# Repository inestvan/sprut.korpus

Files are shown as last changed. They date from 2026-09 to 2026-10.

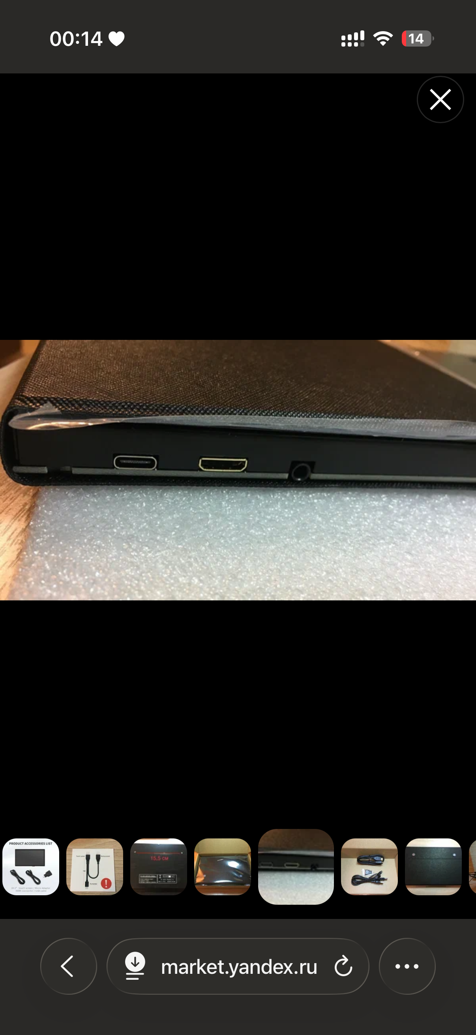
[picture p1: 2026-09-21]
docs/monitor/displayA_side_ports.png

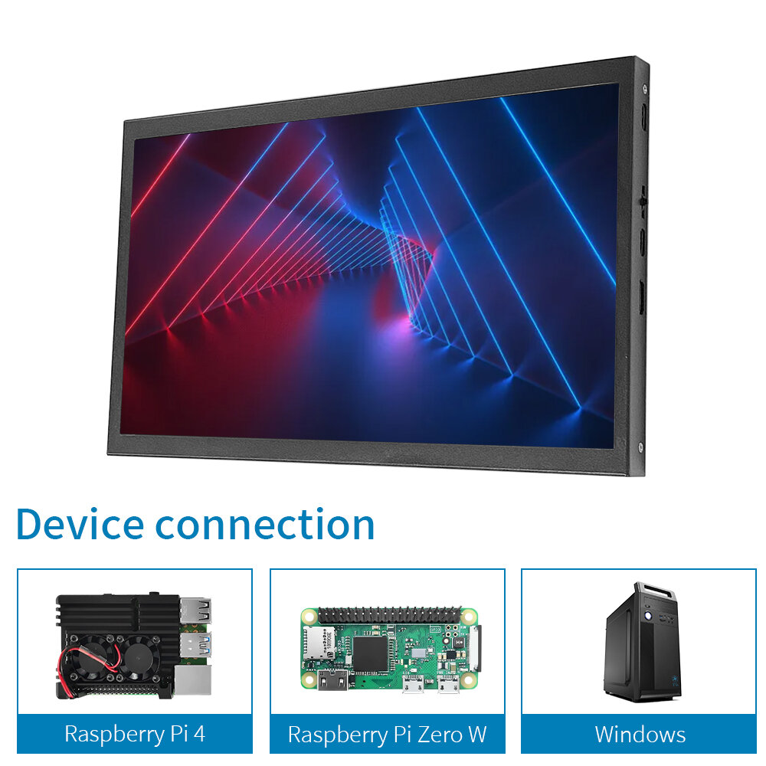
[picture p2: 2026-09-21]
docs/monitor/other_variant/jrp1133_front_angle.jpg

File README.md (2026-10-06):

# SPRUT — корпус изделия (10.1" монитор + Raspberry Pi 4B)

Печать: **Creality K2 Plus, PETG**. Модель параметрическая (OpenSCAD), все размеры
компонентов вынесены в начало файла `cad/sprut_korpus.scad`.

| Файл | Что это |
|---|---|
| `cad/sprut_korpus.scad` | исходник модели, параметры в начале файла |
| `stl/sprut_box.stl` | коробка (задняя стенка + борта), печатать как есть |
| `stl/sprut_bezel.stl` | лицевая рамка, уже развёрнута лицом вниз |
| `preview/*.png` | рендеры для проверки |
| `preview/scheme_placement.png` | схема: что куда ставится в корпусе (исходник `docs/scheme_placement.svg`) |
| `preview/scheme_wiring.png` | схема проводки и порядок сборки (исходник `docs/scheme_wiring.svg`) |
| `tools/diagrams/` | генераторы схем: `python3 tools/diagrams/wiring.py` пишет SVG в `docs/`, `node tools/diagrams/shot.mjs` делает PNG |
| `docs/components.md` | размеры компонентов, источники, что нужно проверить |

Наружный габарит при текущих параметрах: **272.2 x 153.4 x 59 мм** (Ш x В x Г).
Оба STL помещаются на стол K2 Plus (350 x 350) одновременно.

## Конструкция

Две детали, монитор загружается **спереди**:

1. **Коробка** — открыта спереди. На задней стенке: 4 стойки Raspberry Pi
   (M2.5), два держателя-«кармана» для DC-DC и RS485 (плата вдвигается в пазы),
   вентиляционные щели, отверстия VESA 100 (M4). Raspberry Pi полностью
   внутри корпуса, наружу её порты не выходят. Плата прижата к ВЕРХНЕМУ борту
   стороной microSD, а перед её разъёмами USB и Ethernet освобождено
   **55.9 мм** — туда заходят вилки с кабелями (USB-A с хвостовиком 40–45 мм,
   RJ45 с колпачком около 47 мм). Схема компоновки: `preview/layout_top.png`.
   Если понадобится вывести порты Pi наружу, поставь `pi_ports_window = true`:
   плата придвинется к нижнему борту и в нём появится окно 54.3 x 20.1 мм.
   В нижнем борту: вырез XT60E-M с двумя отверстиями под винты, отверстие BNC,
   окно RJ45, вентиляция. В верхнем борту — вентиляция.
   По левому и правому краю — каналы шириной 8 мм с шестью бобышками под
   резьбовые вставки M3. Внутренние стенки каналов и полки по длинным
   бортам держат монитор на нужной глубине.
   Разъёмы монитора («10 inch portable display», Display-A) стоят на **правом**
   торце (вид спереди): Type-C, mini HDMI, гнездо наушников. Поэтому справа вместо узкого канала
   сделан **отсек шириной 18 мм** под угловые штекеры. На уровне монитора с
   этой стороны стенки нет вообще: внутренняя стенка поднимается только до
   плоскости полки. Бобышки справа только по углам. По X монитор держит
   ребро 2.5 мм на лицевой рамке — оно остаётся выше штекера. Ниже полки в
   стенке окно 5–80 мм от нижнего края: через него проходят кабели монитора
   и штекеры micro-HDMI/USB-C Pi. Сенсорные кнопки
   монитора на его задней панели в корпусе недоступны — яркость выставить до
   сборки (см. docs/components.md).
   Raspberry Pi стоит со стороны разъёмов монитора: её micro-HDMI и USB-C
   смотрят в окно отсека, перед ними свободно 35 мм до наружного борта
   (`pi_hdmi_free`), HDMI-шлейф до монитора 15–20 см. Порты USB/Ethernet
   смотрят к верхнему борту, перед ними свободно 55.9 мм под вилки.
   Держатели DC-DC и RS485 стоят компактным блоком у нижнего борта левее Pi,
   платы вдвигаются сверху. Крепление VESA 100 сдвинуто на 16 мм влево
   (`vesa_dx`), чтобы отверстия не попадали под плату Pi. Разъёмы XT60,
   BNC, RJ45 — в левой части нижнего борта.
   Параметры: `mon_conn_side`, `mon_conn_y`, `bay_w`, `bezel_rib_h`,
   `wheel_slot`, `bay_boss_extra`.
2. **Лицевая рамка** — 3 мм, окно экрана с фаской 45°, 5 винтов M3 с потаем,
   ребро 2.5 мм вдоль торца монитора со стороны отсека разъёмов.

Порядок сборки: вставки M3 в бобышки (паяльник) → Pi на стойки (торцом USB к
нижнему борту, компонентами к экрану) → DC-DC и RS485 вдвинуть в держатели →
XT60/BNC/RJ45 в нижний борт → DC-DC и RS485 вдвинуть в держатели сбоку →
на монитор надеть угловые HDMI и Type-C, кабели
пропустить через окно во внутренней стенке за монитор → монитор положить спереди на полки (по периметру
рекомендую двусторонний вспененный скотч 1 мм) → рамка на 5 винтов M3x8.

## Что обязательно проверить перед печатью

Полный список с размерами и источниками — в `docs/components.md`. Коротко:

- **Монитор.** Заложен замер владельца: 237.2 x 145.4 x 14.5 мм (полная
  толщина, задняя сторона считается плоской — монитор лежит задней кромкой
  на полках шириной 2.5 мм). Активная область не замерялась: окно рамки
  224 x 126.5 по центру. Если светящаяся область смещена относительно
  габарита или задняя сторона не плоская (плата драйвера выступает бугром,
  а по краю толщина меньше) — сообщи, поправлю `view_dx/view_dy` и полки.
- **Разъёмы монитора.** Сторона и координаты сняты с фото с Маркета
  (см. `docs/components.md`, точность ±3 мм): правый торец, Type-C 25,
  mini HDMI 45, наушники 65 мм от низа. Один Type-C несёт и питание, и тач.
  Кабели — только **угловые** (90°) или плоские FPC-шлейфы: прямой HDMI-штекер
  требует ~40 мм и в отсек не влезет.
- **DC-DC 60V/3A (CR-6030L).** Точных размеров в сети нет; по фото и листингу
  ~43 x 21 мм, высота ~14 мм с конденсаторами. Держатель параметрический
  (`dcdc_l, dcdc_w`), подстрой под замер.
- **RS485-TTL.** 34 x 18 x 9 мм (с фото продавца) — заложено. Просвет паза
  держателя 18.9 мм (плата + 0.9), есть заходная фаска. Параметры `rs_gap_w`,
  `rs_gap_t`, `rs_lead`.
- **DC-DC.** Держатель оставлен как в первой версии (просвет 21.35, плата
  + 0.35, без фаски) — плата села хорошо. Параметры `dcdc_gap_w`,
  `dcdc_gap_t`, `dcdc_lead`, они независимы от RS485.
- **RJ45.** Гнездо на фото — под пайку в плату (8P8C, 15.9 x 21.6 x 13.4).
  Заложено окно 16.8 x 14.3 мм; само гнездо нужно припаять на плату и
  закрепить у стенки. Если возьмёшь панельный RJ45 (keystone / проходной с
  фланцем), скажи — заменю вырез.
- **BNC.** Заложено круглое отверстие Ø9.9 под резьбу 3/8"-32. Если у твоего
  разъёма есть лыска против проворота, поставь `bnc_flat = 9.0` (D-отверстие).

## Печать (K2 Plus, PETG)

- Сопло 0.4, слой 0.2, стенки 4 периметра (1.6 мм), верх/низ 5 слоёв,
  заполнение 25–30 % gyroid.
- Коробка — задней стенкой вниз (как в STL), **без поддержек**: стойки,
  бобышки и держатели вертикальные, полки под монитор с фаской 45°, окна в
  бортах перекрываются мостами до 55 мм (окно портов Pi) — для PETG
  включи охлаждение мостов.
- Рамка — лицом вниз (как в STL), без поддержек. Для гладкого лица —
  гладкий PEI лист. Потай под винты печатается конусом вверх.
- Держатель RS485 имеет заходную фаску 4 мм на открытом конце; у DC-DC
  фаски нет, он повторяет первую версию.
- Резьбовые вставки M3 (OD 4.5–4.6, длина 5–6): отверстие 4.0 мм.
  Саморезы Pi M2.5 в отверстие 2.2 мм. XT60 — саморезы M3 в отверстие 2.5 мм
  (или поставь `xt_screw_d = 3.2` под болт с гайкой).
- Температура сопла PETG 240–250 °C, стол 75–80 °C, клей/лак на стол,
  дверь принтера закрыть.

## Крепёж

| Позиция | Кол-во |
|---|---|
| Вставка резьбовая M3 (OD 4.5, L 5–6) | 5 |
| Винт M3x8 потайной | 5 |
| Саморез M2.5x6 (Pi) | 4 |
| Саморез M3x8 (XT60E-M) | 2 |
| Винт M4 (VESA 100) | 4, по желанию |

## Проверка геометрии

`tools/verify_stl.py` режет STL плоскостями и сверяет размеры проёма под
монитор, стоек Pi, вырезов в нижнем борту, окна рамки, отверстий под винты
и пазов держателей с заданными значениями.

## Регенерация STL

```bash
openscad -o stl/sprut_box.stl   -D 'part="box"'   cad/sprut_korpus.scad
openscad -o stl/sprut_bezel.stl -D 'part="bezel"' cad/sprut_korpus.scad
```

## Как закреплён монитор

Без винтов: монитор зажат между полками коробки (сзади) и лицевой рамкой
(спереди), по бокам его держат борта и внутренние стенки каналов с зазором
1 мм. Со стороны разъёмов внутренняя стенка и полка прерваны окном под
кабели, монитор там держат участки стенки выше и ниже окна. Разрезы — `preview/section_y.png` и `preview/section_x.png`.
Между рамкой и монитором заложен зазор 0.3 мм: проложи по периметру
вспененный двусторонний скотч 0.5–1 мм, он выберет зазор и защитит стекло.

Разрезы генерируются из `cad/slice.scad` (параметры `which`, `axis`, `pos`):

```bash
openscad -o sec.svg -D 'which="box"' -D 'axis="y"' -D 'pos=76.7' cad/slice.scad
```

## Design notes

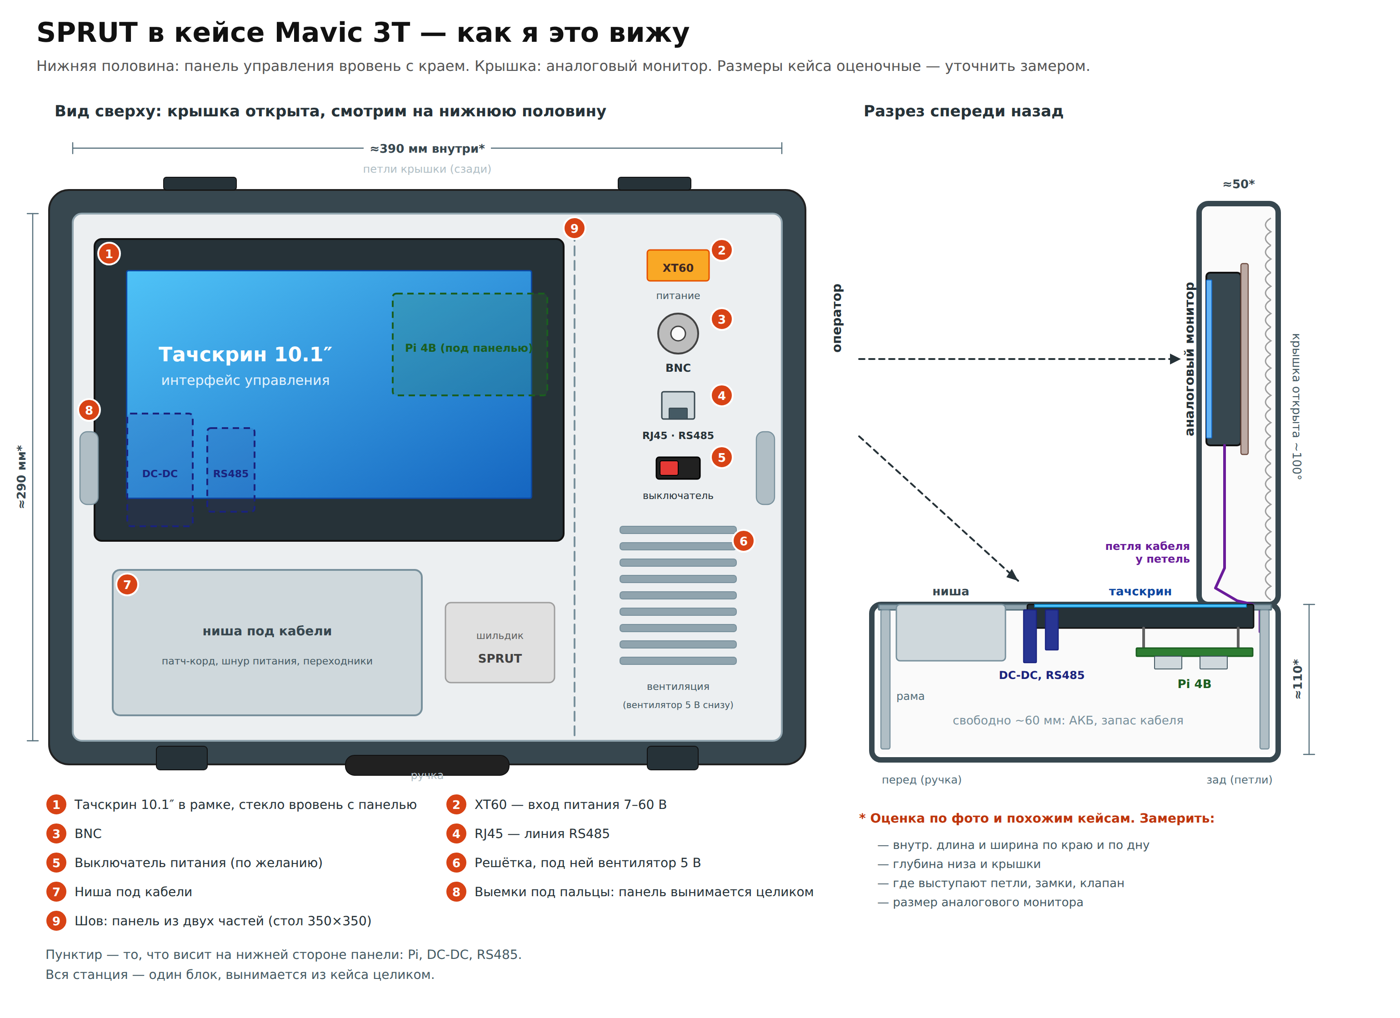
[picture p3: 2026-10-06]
preview/case_mavic3t_concept.png

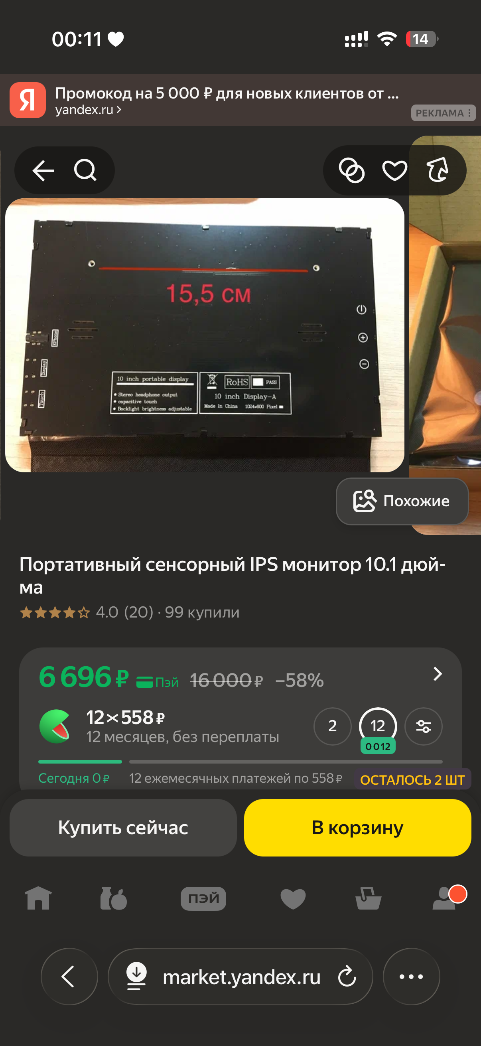
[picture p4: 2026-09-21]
docs/monitor/displayA_back_yandex.png

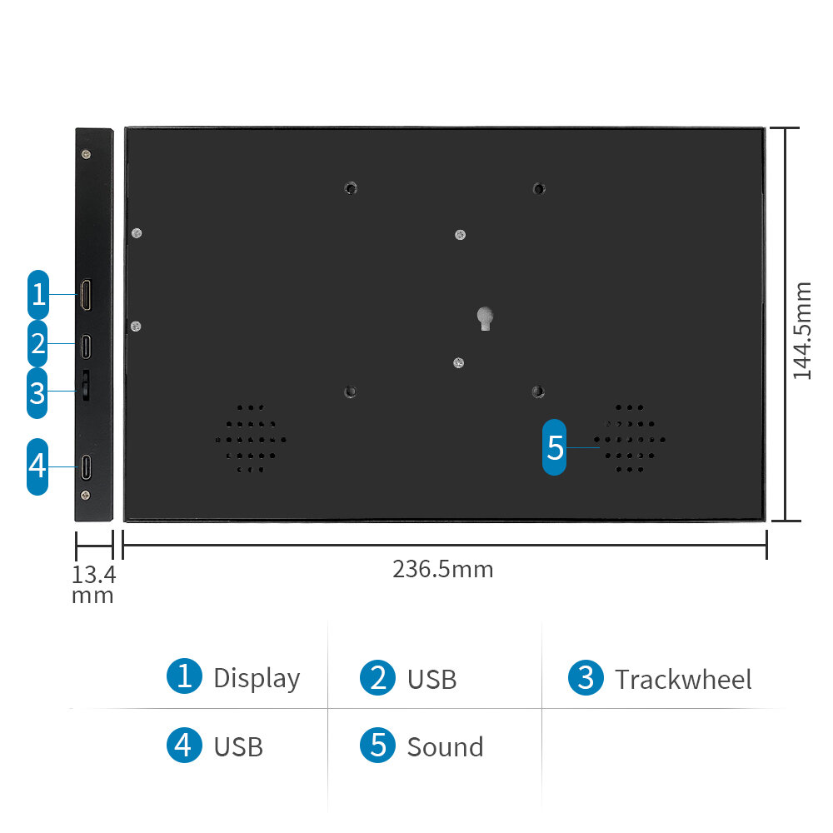
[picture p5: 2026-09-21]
docs/monitor/other_variant/jrp1133_back_ports.jpg

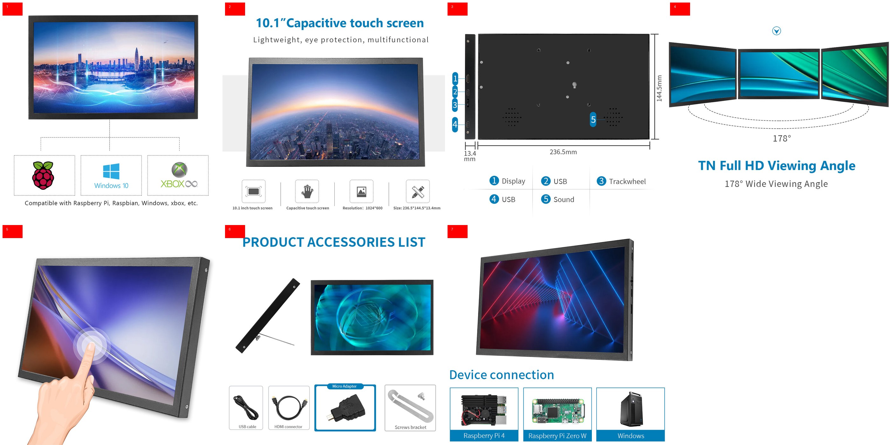
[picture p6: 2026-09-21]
docs/monitor/other_variant/jrp1133_all_photos.jpg

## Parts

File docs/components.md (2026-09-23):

# Компоненты: размеры, источники, что уточнить

Статус: ✅ по даташиту / официальному чертежу, ⚠️ оценка (нужен замер), ❌ не найдено.

## Raspberry Pi 4 Model B ✅

Источник: официальный datasheet, Release 1.1 (март 2024), раздел
«Mechanical Specification».

| Параметр | Значение |
|---|---|
| Плата | 85 x 56 мм, радиус углов 3 мм, толщина 1.6 |
| Отверстия | 4 x Ø2.7 (M2.5), сетка 58 x 49, отступ от краёв 3.5 |
| USB-C | центр 11.2 от левого края, высота 3.2 |
| micro-HDMI 0 / 1 | центры 26.0 и 39.5, высота 3.0 |
| Аудио 3.5 | центр 54.0, высота 6.0 |
| Правый торец: USB2 | центр 9.0 от нижнего края, 13.1 x 16.0 |
| Правый торец: USB3 | центр 27.0, 13.1 x 16.0 |
| Правый торец: Ethernet | центр 45.75, 16.0 x 13.5 |
| Выступ USB/ETH за край | ~2.5 |
| GPIO 2x20 | центр 32.5 от левого края, высота 8.5 |

В модели: Pi лежит на задней стенке коробки на стойках 6 мм, компонентами к
экрану, полностью внутри корпуса. Стоит у ПРАВОЙ стенки, со стороны разъёмов
монитора (`pi_near_bay = true`), повёрнута так, что длинный торец с
USB-C / micro-HDMI / аудио смотрит в окно стенки отсека.

| Параметр | Значение |
|---|---|
| Плата занимает | X 178.2…234.2, Y 7…92 |
| Торец micro-HDMI до стенки отсека | 18 мм |
| Свободно перед micro-HDMI / USB-C до наружного борта | 35 мм (сквозь окно в отсек), `pi_hdmi_free` |
| USB-C / micro-HDMI 0 / micro-HDMI 1 / аудио | Y 18.2 / 33 / 46.5 / 61 |
| Разъёмы монитора Type-C / mini HDMI | Y 29 / 49 |
| Край microSD до нижнего борта | 4 мм (карта выступает ~2.5) |
| Торцы USB/Ethernet | Y 94.5, свободно до верхнего борта 55.9 мм |

HDMI от Pi до монитора: micro-HDMI Pi на Y 33 или 46.5, mini-HDMI монитора
на Y 49 и выше на 30 мм по глубине. Перед разъёмами Pi 35 мм — влезает и
обычный прямой micro-HDMI штекер с хвостовиком. Шлейф 15–20 см, со стороны
монитора угловой mini-HDMI.

Крепление VESA 100 сдвинуто на 16 мм влево (`vesa_dx`): иначе нижнее правое
отверстие приходилось под плату Pi, прямо под выводы GPIO.
USB/Ethernet по-прежнему втыкаются изнутри, для них оставлено 55.9 мм.

Кнопки монитора (на его задней панели у левого края) теперь над пустым
участком задней стенки корпуса — при желании там можно сделать лючок.

## XT60E-M (Amass) — панельный, папа ✅

Источник: чертёж Amass XT60E-M (Changzhou Amass Electronics).

| Параметр | Значение |
|---|---|
| Фланец | 27.0 x 8.1 |
| Крепёжные отверстия | 2 x Ø3.0, межцентровое 20.0 |
| Тело (вырез в панели) | 15.5 x 8.1, углы скошены |
| Глубина за фланцем | 9.5 (корпус) + 4.0 (контакты) |
| Полная длина | 16.7 |
| Контакты | Ø4.3, шаг 7.2 |

В модели: вырез 16.1 x 8.7 (зазор 0.3), отверстия Ø2.5 под саморез M3.

## Расположение держателей DC-DC и RS485

Компактный блок вплотную к нижнему борту, левее Raspberry Pi и отверстия
VESA, длинной стороной вдоль высоты корпуса. Платы вдвигаются сверху (со
стороны верхнего борта), торцевые упоры внизу. DC-DC ближе к Pi, RS485 ближе
к RJ45.

| Держатель | Основание X | Основание Y | Просвет паза |
|---|---|---|---|
| RS485 | 118.7…139.6 | 4…44 | 18.9 x 2.0 |
| DC-DC | 141.6…164.9 | 4…53 | 21.35 x 1.95 |

Над блоком свободная зона 46 x 42 мм для вдвигания плат, в задней стенке
там пять вентиляционных щелей. Отверстие VESA (170.1, 26.7) в 3 мм правее
блока и в 6 мм левее Pi.

## RS485-TTL модуль ⚠️ (размеры с фото продавца)

34 x 18 мм, высота 9 мм (DC-DC изолятор — самый высокий элемент). Крепёжных
отверстий на фото нет, поэтому в модели держатель-«карман»: плата вдвигается
в пазы сбоку, торцевой упор с одной стороны, на открытом конце заходная
фаска 4 мм. Зазоры: по ширине 0.9 мм суммарно (`rs_gap_w`), по толщине
0.4 мм (`rs_gap_t`). Просвет паза 18.9 x 2.0 мм. У DC-DC свои параметры
(`dcdc_gap_w` 0.35, `dcdc_gap_t` 0.35, без фаски), просвет 21.35 x 1.95 —
как в первой версии, плата села хорошо.

## DC-DC 60V/3A buck, маркировка CR-6030L ⚠️

По маркировке платы «60V/3A 降压模块», два электролита (100 мкФ 63 В и
330 мкФ 35 В), дроссель 22 мкГн. Листинг на AliExpress (1005006203232387)
даёт только «4 x 2 x 1 см, 15 г». Точного чертежа в сети нет.

Моя оценка по фото (по диаметру конденсаторов 8 мм): **43 x 21 мм, высота
~14 мм** (конденсаторы 12 + плата 1.6). Два отверстия Ø3 по диагонали
(у IN+ и у OUT−). Просьба замерить: длину, ширину, высоту, и есть ли
отверстия. В модели держатель-«карман» с параметрами `dcdc_l`, `dcdc_w`,
`dcdc_pcb_t`, `dcdc_comp_h`.

## Монитор 10.1" «10 inch portable display / Display-A» ✅ (по фото владельца)

Точная модель найдена владельцем на Яндекс Маркете (карточка 102591172820,
«Портативный сенсорный IPS монитор 10.1 дюйма»). Скриншоты в `docs/monitor/`:
вид сзади, торец с разъёмами, размеры спереди. На задней панели шелкография
«10 inch portable display — Stereo headphone output, capacitive touch,
Backlight brightness adjustable» и «10 inch Display-A, 1024x600».
Производитель не указан, это безымянный OEM; чертежей в сети нет, а
одноимённые серии Elecrow «Display-H/B» — другие изделия (micro-USB, 20 мм).
Ранее найденный KEPIFO JRP1133 (папка `other_variant`) — похожий, но другой
вариант платы: у него колёсико и два Type-C, у этого их нет.

| Параметр | Значение | Источник |
|---|---|---|
| Габарит по продавцу | 235 x 143 | фото с линейкой |
| Габарит по замеру владельца | 237.2 x 145.4 x 14.5 | замер (заложено) |
| Экран | IPS 1024x600, ёмкостный тач 5 точек | шелкография |
| Крепёжные отверстия сзади | 2 шт, шаг 155 мм, на 29 мм от верхнего края, 40 мм от левого (вид сзади) | фото |
| Кнопки | сенсорные ⏻ / + / − на ЗАДНЕЙ панели, у левого края (вид спереди), ~9 мм от края, 48 / 66 / 84 мм от низа | фото |

**Порты — на ПРАВОМ торце (вид спереди)**, по центру толщины. Координаты от
НИЖНЕГО края монитора, точность ±3 мм (сняты с фото задней панели):

| Элемент | От нижнего края | Назначение |
|---|---|---|
| Type-C («Touch») | 25 | питание 5 В и тачскрин по одному кабелю |
| mini HDMI («Display», гнездо 11.2 мм) | 45 | видео |
| Гнездо 3.5 мм («Earphone») | 65 | наушники, не используется |

Что заложено в модель: `mon_conn_side = "right"`, отсек 18 мм без стенки на
уровне монитора, окно под кабели в стенке ниже полки на 12…80 мм от нижнего
края, прорезь под колёсико отключена (`wheel_slot = false`).

**Важно про кнопки.** Питание, «+» и «−» — сенсорные площадки на задней
панели монитора. В закрытом корпусе задняя панель смотрит внутрь, к Pi, и
кнопки недоступны. Обычно такие мониторы включаются сами при подаче питания
и помнят яркость — выставь яркость до окончательной сборки. Если нужен
доступ, скажи: можно сделать лючок в задней стенке напротив кнопок, но там
сейчас стоит Raspberry Pi, её придётся сдвинуть.

## RJ45 ⚠️

На фото — гнездо 8P8C под пайку в плату (типовое: 15.9 x 21.6 x 13.4,
окно под вилку ~12 x 12). В модели окно в борту 16.8 x 14.3 (зазор 0.4).
Гнездо нужно закрепить на плате, прижатой к борту изнутри. Альтернатива —
панельный проходной RJ45 (keystone, вырез 14.5 x 16.0 или фланцевый
D-типа) — заменю вырез по запросу.

## BNC панельный ✅/⚠️

Стандарт для BNC bulkhead с резьбой 3/8"-32 UNEF: отверстие Ø9.5–9.7,
D-образное с лыской 9.0 (у части разъёмов лыски нет). Толщина панели 3 мм
проходит по длине резьбы (~7 мм с гайкой, гровером и лепестком).
В модели: круглое Ø9.9 (`bnc_flat = 0`); для D-отверстия — `bnc_flat = 9.0`.

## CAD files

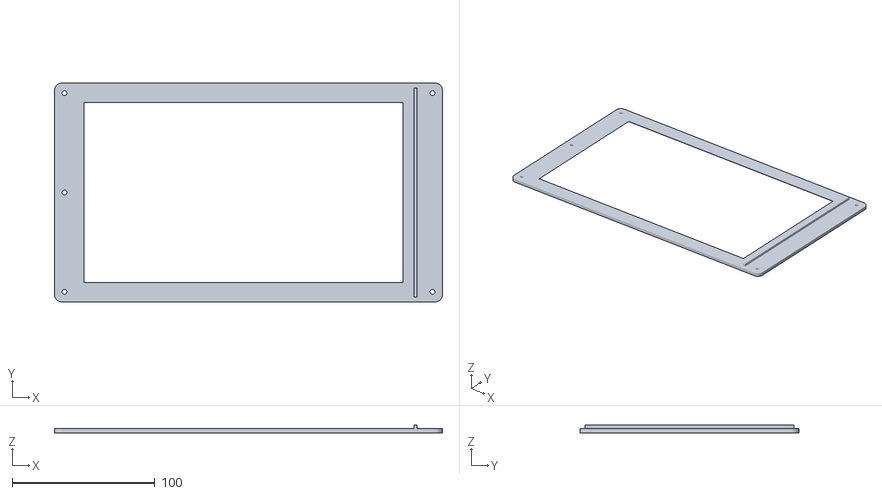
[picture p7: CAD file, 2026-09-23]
stl/sprut_bezel.stl
272.2 x 153.4 x 5.50

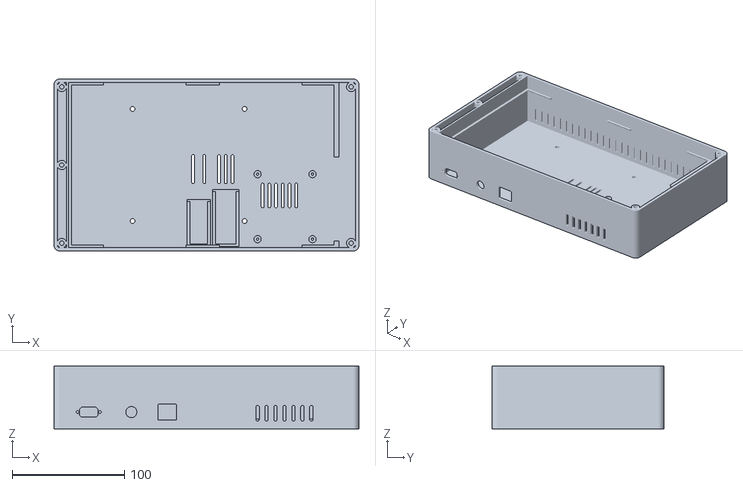
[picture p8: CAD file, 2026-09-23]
stl/sprut_box.stl
272.2 x 153.4 x 56.0

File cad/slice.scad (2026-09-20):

use </home/user/sprut.korpus/cad/sprut_korpus.scad>
which = "box";   // box | bezel | mon | pi | cards
axis  = "y";     // y: разрез плоскостью Y=pos ; x: плоскостью X=pos
pos   = 76.7;
module sel() {
  if (which == "box")   box();
  if (which == "bezel") bezel_world();
  if (which == "mon")   ghost_monitor();
  if (which == "pi")    ghost_pi();
  if (which == "cards") ghost_cards();
  if (which == "plugs") ghost_plugs();
}
// результат: 2D, X = координата вдоль разреза, Y = глубина Z корпуса
if (axis == "y") projection(cut=true) rotate([-90, 0, 0]) translate([0, -pos, 0]) sel();
else             projection(cut=true) rotate([-90, 0, 0]) rotate([0, 0, -90]) translate([-pos, 0, 0]) sel();

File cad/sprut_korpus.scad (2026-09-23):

// =====================================================================
//  SPRUT — корпус: 10.1" монитор + Raspberry Pi 4B + DC-DC 60V buck
//  + RS485-TTL + XT60E-M + RJ45 + BNC
//
//  Печать: Creality K2 Plus, PETG. Все размеры в мм.
//
//  Конструкция из двух деталей:
//    "box"   — коробка: задняя стенка + 4 борта, открыта СПЕРЕДИ. На задней
//              стенке стойки Pi и держатели модулей; в бортах вырезы под
//              разъёмы; по бокам два канала с бобышками под вставки M3.
//              Монитор укладывается спереди на полки, затем прикручивается
//              лицевая рамка. Печатать как смоделирована (задней стенкой вниз).
//    "bezel" — лицевая рамка с окном экрана, 6 винтов M3 с потаем.
//              В STL уже развёрнута лицевой стороной вниз.
//    "assembly" — сборка с макетами компонентов (только для просмотра).
//
//  Система координат: X — ширина, Y — высота (вид спереди), Z — от наружной
//  плоскости задней стенки (Z=0) к лицевой рамке.
// =====================================================================

part = "assembly";   // [box, bezel, assembly]

$fn = 48;
eps = 0.01;

// ---------------------------------------------------------------------
// ПАРАМЕТРЫ — печать / стенки
// ---------------------------------------------------------------------
wall     = 3.0;    // толщина бортов
back_t   = 3.0;    // толщина задней стенки
bezel_t  = 3.0;    // толщина лицевой рамки
corner_r = 5.0;    // радиус наружных углов (вид спереди)
clr      = 1.0;    // зазор монитор/стенки на сторону
ch_w     = 8.0;    // ширина боковых каналов под бобышки (= диаметр бобышки)
in_wall  = 2.0;    // толщина внутренней стенки канала
shelf_w  = 2.5;    // ширина полки под край монитора

// ---------------------------------------------------------------------
// ПАРАМЕТРЫ — монитор 10.1" 1024x600 (JRP1133 DCT)
// Габарит по замеру владельца: 237.2 x 145.4 x 14.5 мм (толщина полная,
// задняя сторона считается плоской — монитор лежит задней кромкой на полках).
// Активная область не замерялась: окно = типовые 222.7 x 125.3 + 1 мм,
// по центру. Если светящаяся область смещена — поправь view_dx / view_dy.
// ---------------------------------------------------------------------
mon_w   = 237.2;   // ширина монитора (габарит)
mon_h   = 145.4;   // высота
mon_t   = 14.5;    // полная толщина монитора
view_w  = 224.0;   // окно в рамке (активная область + ~1 мм)
view_h  = 126.5;
view_dx = 0.0;     // смещение окна от центра панели (+ вправо)
view_dy = 0.0;     // (+ вверх)
drv_zone = 12.0;   // свободная глубина за монитором под кабели
// Разъёмы монитора «10 inch portable display / Display-A» (по фото владельца и
// продавца, см. docs/components.md). Все на ПРАВОМ торце (вид спереди), по центру
// толщины. От НИЖНЕГО края монитора, точность ±3 мм:
//   Type-C (питание + тач) 25, mini HDMI 45, гнездо наушников 65.
// Сзади на панели сенсорные кнопки питание / + / − (в корпусе недоступны).
// Со стороны разъёмов вместо узкого канала — отсек шириной bay_w под угловые
// штекеры; на уровне монитора там нет стенки; ниже полки в стенке окно под кабели.
mon_conn_side = "right";    // "left" | "right" — сторона разъёмов, вид спереди
mon_conn_y    = [5, 80];    // окно под кабели в стенке ниже полки (от нижнего края монитора);
                            // при Pi у отсека через него же проходят штекеры micro-HDMI/USB-C Pi
mon_hdmi_y    = 45;         // центр mini HDMI (макет)
mon_usbc_y    = 25;         // центр Type-C (макет)
mon_jack_y    = 65;         // гнездо наушников 3.5 мм (макет, не используется)
mon_wheel_y   = 0;          // у этого варианта колёсика нет
mon_conn_z    = 7.0;        // ось разъёмов от лицевого стекла (середина толщины)
wheel_slot    = false;      // прорезь под колёсико — у этого монитора не нужна
wheel_slot_l  = 22;
wheel_slot_h  = 8;
bay_w         = 18.0;       // от торца монитора до внутренней грани наружного борта
plug_len      = 13.0;       // выступ углового штекера от торца монитора (макет)
// полки под длинные края панели: сегменты [x_start, длина] от левого края панели
shelf_segs = [[0, 30], [mon_w/2 - 15, 30], [mon_w - 30, 30]];

// ---------------------------------------------------------------------
// ПАРАМЕТРЫ — Raspberry Pi 4B (официальный чертёж, datasheet rev 1.1)
// Pi лежит на задней стенке, компонентами к экрану, торцом USB/ETH к
// нижнему борту. Плата ПОЛНОСТЬЮ ВНУТРИ корпуса: наружу её порты не выходят,
// всё втыкается изнутри. Поэтому плата отодвинута вплотную к ВЕРХНЕМУ борту
// (со стороны microSD), а перед разъёмами USB/Ethernet освобождена вся
// оставшаяся высота полости — туда заходят вилки с кабелями.
// ---------------------------------------------------------------------
pi_l = 85.0;  pi_w = 56.0;  pi_pcb_t = 1.6;
pi_hole_dx = 58.0; pi_hole_dy = 49.0; pi_hole_off = 3.5;
pi_standoff_h = 6.0;  pi_standoff_d = 6.5;
pi_screw_d    = 2.2;   // саморез M2.5 в PETG (2.0 — под метчик M2.5)
pi_usb2_y = 9.0;  pi_usb3_y = 27.0;  pi_eth_y = 45.75;   // центры по короткой стороне
pi_usb_w  = 13.1; pi_usb_h = 16.0;   pi_eth_w = 16.0; pi_eth_h = 13.5;
pi_port_overhang = 2.5;   // выступ USB/ETH за край платы
pi_ports_window = false;  // true: порты Pi наружу через окно в борту; false: Pi полностью внутри
pi_far_gap  = 4.0;        // край платы со стороны microSD до борта (карта выступает ~2.5 мм)
pi_near_bay = true;       // true: Pi у стенки со стороны разъёмов монитора; false: у противоположной
pi_hdmi_free = 35.0;      // свободно от торца micro-HDMI/USB-C Pi до наружного борта (сквозь окно в отсек)
pi_win_clr  = 1.5;        // зазор окна вокруг разъёмов Pi (только при pi_ports_window)

// ---------------------------------------------------------------------
// ПАРАМЕТРЫ — DC-DC 60V/3A buck (CR-6030L). Габарит платы — ОЦЕНКА по фото
// и листингу (~4x2 см). Поправь после замера.
// ---------------------------------------------------------------------
dcdc_l = 43.0;  dcdc_w = 21.0;  dcdc_pcb_t = 1.6;  dcdc_comp_h = 13.0;

// ---------------------------------------------------------------------
// ПАРАМЕТРЫ — RS485-TTL модуль (по фото продавца 34 x 18 x 9)
// ---------------------------------------------------------------------
rs_l = 34.0;  rs_w = 18.0;  rs_pcb_t = 1.6;  rs_comp_h = 8.0;

// Зазоры в держателях плат, отдельно для каждого.
// DC-DC оставлен как в первой версии — плата села хорошо, не трогать.
dcdc_gap_w = 0.35;  dcdc_gap_t = 0.35;  dcdc_lead = 0.0;
// RS485 входил туго, паз расширен и добавлена заходная фаска.
rs_gap_w   = 0.9;   rs_gap_t   = 0.40;  rs_lead   = 4.0;

// ---------------------------------------------------------------------
// ПАРАМЕТРЫ — панельные разъёмы (нижний борт)
// ---------------------------------------------------------------------
// XT60E-M (даташит Amass): фланец 27.0 x 8.1, отв. Ø3.0 шаг 20.0,
// тело 15.5 x 8.1 (восьмиугольник), глубина за фланцем 9.5 + контакты 4.0
xt_body_l = 15.5; xt_body_w = 8.1; xt_hole_pitch = 20.0;
xt_cut_clr = 0.3;  xt_screw_d = 2.5;   // 2.5 — саморез M3 в пластик; 3.2 — под болт M3
// RJ45 гнездо на плату (8P8C, корпус 15.9 x 21.6 x 13.4)
rj_w = 16.0; rj_h = 13.5; rj_clr = 0.4;
// BNC панельный, резьба 3/8"-32: отверстие Ø9.6. bnc_flat>0 — D-образное
// отверстие с лыской (размер «по лыске»), 0 — круглое.
bnc_d = 9.6; bnc_flat = 0; bnc_clr = 0.15;

// ---------------------------------------------------------------------
// ПАРАМЕТРЫ — крепёж рамки, VESA
// ---------------------------------------------------------------------
insert_d = 4.0;        // отверстие под резьбовую вставку M3 (OD 4.5-4.6) в PETG
insert_depth = 8.0;
bz_screw_d = 3.4;      // сквозное под M3 в рамке
bz_csk_d = 6.4;        // потай
bezel_rib_h = 2.5;     // ребро рамки, фиксирующее монитор по X со стороны отсека
vesa = 100;            // 0 = без VESA; 75 или 100
vesa_screw_d = 4.3;    // M4
vesa_dx = -16;         // сдвиг центра VESA по ширине: правые отверстия левее платы Pi
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

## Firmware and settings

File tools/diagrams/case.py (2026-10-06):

import os
DOCS=os.path.join(os.path.dirname(os.path.abspath(__file__)),"..","..","docs")
o=[]
def rect(x,y,w,h,fill,st="#2c3e50",sw=1.5,rx=4,dash=None,op=1):
    d=f' stroke-dasharray="{dash}"' if dash else ''
    o.append(f'<rect x="{x}" y="{y}" width="{w}" height="{h}" rx="{rx}" fill="{fill}" fill-opacity="{op}" stroke="{st}" stroke-width="{sw}"{d}/>')
def t(x,y,s,size=14,f="#111",anc="start",w="normal",rot=None):
    tr=f' transform="rotate({rot} {x} {y})"' if rot else ''
    o.append(f'<text x="{x}" y="{y}" font-size="{size}" fill="{f}" text-anchor="{anc}" font-weight="{w}"{tr}>{s}</text>')
def line(pts,col,w=2,dash=None):
    d=f' stroke-dasharray="{dash}"' if dash else ''
    p=" ".join(f"{x},{y}" for x,y in pts)
    o.append(f'<polyline points="{p}" fill="none" stroke="{col}" stroke-width="{w}" stroke-linejoin="round" stroke-linecap="round"{d}/>')
def circ(x,y,r,fill,st="#111",sw=1.5): o.append(f'<circle cx="{x}" cy="{y}" r="{r}" fill="{fill}" stroke="{st}" stroke-width="{sw}"/>')
def num(x,y,n):
    circ(x,y,12,"#d84315","#fff",2); t(x,y+5,str(n),13,"#fff","middle","bold")
def dim_h(x1,x2,y,label):
    line([(x1,y),(x2,y)],"#546e7a",1.2); line([(x1,y-6),(x1,y+6)],"#546e7a",1.2); line([(x2,y-6),(x2,y+6)],"#546e7a",1.2)
    rect((x1+x2)/2-70,y-11,140,20,"#fff","none",0); t((x1+x2)/2,y+5,label,13,"#37474f","middle","bold")
def dim_v(x,y1,y2,label):
    line([(x,y1),(x,y2)],"#546e7a",1.2); line([(x-6,y1),(x+6,y1)],"#546e7a",1.2); line([(x-6,y2),(x+6,y2)],"#546e7a",1.2)
    t(x-8,(y1+y2)/2,label,13,"#37474f","middle","bold",rot=-90)

W,H=1540,1120
t(40,46,"SPRUT в кейсе Mavic 3T — как я это вижу",30,"#111",w="bold")
t(40,78,"Нижняя половина: панель управления вровень с краем. Крышка: аналоговый монитор. Размеры кейса оценочные — уточнить замером.",16,"#555")

# ================= ВИД СВЕРХУ =================
S=2.0; X0,Y0=80,235          # мм -> px
def P(x,y): return X0+x*S, Y0+y*S
IW,IH=390,290
t(X0-20,128,"Вид сверху: крышка открыта, смотрим на нижнюю половину",17,"#263238",w="bold")
# кейс снаружи
rect(X0-26,Y0-26,IW*S+52,IH*S+52,"#37474f","#212121",2,rx=22)
for hx in (70,320):   # петли
    rect(*P(hx-20,-20),80,14,"#263238","#111",1,rx=3)
for lx in (60,330):   # замки
    rect(*P(lx-14,IH+3),56,26,"#263238","#111",1,rx=4)
rect(*P(150,IH+8),180,22,"#212121","#111",1,rx=10); t(P(195,0)[0],P(0,IH+19)[1]+4,"ручка",12,"#b0bec5","middle")
t(P(195,0)[0],Y0-45,"петли крышки (сзади)",12,"#b0bec5","middle")
# панель
rect(*P(0,0),IW*S,IH*S,"#eceff1","#90a4ae",2,rx=10)
# шов
SEAM=276
line([P(SEAM,2),P(SEAM,IH-2)],"#78909c",2,"10 6")
# экран-модуль
rect(*P(12,14),258*S,166*S,"#263238","#111",2,rx=8)
ax,ay=12+(258-222.7)/2,14+(166-125.3)/2-3
o.append(f'<defs><linearGradient id="scr" x1="0" y1="0" x2="1" y2="1"><stop offset="0" stop-color="#4fc3f7"/><stop offset="1" stop-color="#1565c0"/></linearGradient></defs>')
rect(*P(ax,ay),222.7*S,125.3*S,"url(#scr)","#0d47a1",1.5,rx=2)
t(P(95,0)[0],P(0,ay+50)[1],"Тачскрин 10.1″",22,"#fff","middle","bold")
t(P(95,0)[0],P(0,ay+63)[1],"интерфейс управления",15,"#e3f2fd","middle")
# под панелью — пунктир
rect(*P(176,44),85*S,56*S,"#2e7d32","#1b5e20",2,dash="7 5",op=0.18); t(P(218,0)[0],P(0,76)[1],"Pi 4B (под панелью)",12,"#1b5e20","middle","bold")
rect(*P(30,110),36*S,62*S,"#283593","#1a237e",2,dash="7 5",op=0.15); t(P(48,0)[0],P(0,145)[1],"DC-DC",11,"#1a237e","middle","bold")
rect(*P(74,118),26*S,46*S,"#283593","#1a237e",2,dash="7 5",op=0.15); t(P(87,0)[0],P(0,145)[1],"RS485",11,"#1a237e","middle","bold")
# правая полоса: разъёмы
cx=333
rect(*P(cx-17,20),34*S,17*S,"#f9a825","#e65100",1.5,rx=3); t(*P(cx,32),"XT60",12,"#3e2723","middle","bold")
t(*P(cx,47),"питание",11,"#455a64","middle")
circ(*P(cx,66),11*S,"#bdbdbd","#424242",2); circ(*P(cx,66),4*S,"#fafafa","#424242",1.5)
t(*P(cx,87),"BNC",12,"#263238","middle","bold")
rect(*P(cx-9,98),18*S,15*S,"#cfd8dc","#37474f",1.5,rx=2); rect(*P(cx-5,107),10*S,6*S,"#455a64","#37474f",1,rx=1)
t(*P(cx,124),"RJ45 · RS485",11,"#263238","middle","bold")
rect(*P(cx-12,134),24*S,12*S,"#212121","#000",1.5,rx=3); rect(*P(cx-10,136),10*S,8*S,"#e53935","#000",1,rx=2)
t(*P(cx,157),"выключатель",11,"#263238","middle")
for i in range(9): rect(*P(cx-32,172+i*9),64*S,4*S,"#90a4ae","#78909c",1,rx=3)
t(*P(cx,262),"вентиляция",11,"#455a64","middle")
t(*P(cx,272),"(вентилятор 5 В снизу)",10,"#455a64","middle")
# передняя полоса: ниша
rect(*P(22,196),170*S,80*S,"#cfd8dc","#78909c",2,rx=8)
t(*P(107,232),"ниша под кабели",14,"#37474f","middle","bold")
t(*P(107,248),"патч-корд, шнур питания, переходники",11,"#455a64","middle")
rect(*P(205,214),60*S,44*S,"#e0e0e0","#9e9e9e",1.5,rx=6); t(*P(235,234),"шильдик",11,"#616161","middle"); t(*P(235,247),"SPRUT",13,"#424242","middle","bold")
for fx in (4,IW-14):  # выемки под пальцы
    rect(*P(fx,120),10*S,40*S,"#b0bec5","#78909c",1.2,rx=8)
# номера
num(*P(20,22),1); num(*P(cx+24,20),2); num(*P(cx+24,58),3); num(*P(cx+24,100),4); num(*P(cx+24,134),5); num(*P(cx+36,180),6)
num(*P(30,204),7); num(*P(9,108),8); num(*P(SEAM,8),9)
# размеры
dim_h(*[P(0,0)[0],P(IW,0)[0]],Y0-72,"≈390 мм внутри*")
dim_v(X0-44,P(0,0)[1],P(0,IH)[1],"≈290 мм*")
# легенда под видом сверху
items=[("1","Тачскрин 10.1″ в рамке, стекло вровень с панелью"),("2","XT60 — вход питания 7–60 В"),("3","BNC"),
       ("4","RJ45 — линия RS485"),("5","Выключатель питания (по желанию)"),("6","Решётка, под ней вентилятор 5 В"),
       ("7","Ниша под кабели"),("8","Выемки под пальцы: панель вынимается целиком"),("9","Шов: панель из двух частей (стол 350×350)")]
ly=Y0+IH*S+70
for i,(n,s) in enumerate(items):
    c,r=i%2,i//2; x=50+c*440; y=ly+r*32
    num(x+12,y,int(n)); t(x+32,y+5,s,14,"#263238")
t(50,ly+170,"Пунктир — то, что висит на нижней стороне панели: Pi, DC-DC, RS485.",14,"#455a64"); t(50,ly+192,"Вся станция — один блок, вынимается из кейса целиком.",14,"#455a64")
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

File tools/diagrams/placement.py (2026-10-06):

import os
DOCS=os.path.join(os.path.dirname(os.path.abspath(__file__)),"..","..","docs")
# Схема 1: что куда встаёт (вид со стороны экрана, монитор и рамка сняты)
W,H,wall = 272.2,153.4,3.0
xc0, xc1 = 13.0, 252.2          # грани полости под монитор
sc = 5.0; ox, oy = 70, 150
def X(x): return ox + x*sc
def Y(y): return oy + (H-y)*sc
out=[]
def rect(x,y,w,h,fill,st="#2c3e50",sw=1.2,dash=None,op=1,rx=0):
    d=f' stroke-dasharray="{dash}"' if dash else ''
    out.append(f'<rect x="{X(x):.1f}" y="{Y(y+h):.1f}" width="{w*sc:.1f}" height="{h*sc:.1f}" rx="{rx}" fill="{fill}" stroke="{st}" stroke-width="{sw}"{d} opacity="{op}"/>')
def circ(x,y,r,fill,st="#455a64",sw=1.2,dash=None):
    d=f' stroke-dasharray="{dash}"' if dash else ''
    out.append(f'<circle cx="{X(x):.1f}" cy="{Y(y):.1f}" r="{r*sc:.1f}" fill="{fill}" stroke="{st}" stroke-width="{sw}"{d}/>')
def txt(x,y,t,s=14,f="#111",anc="middle",w="normal",rot=None,px=False):
    xx,yy=(x,y) if px else (X(x),Y(y))
    tr=f' transform="rotate({rot} {xx:.1f} {yy:.1f})"' if rot else ''
    out.append(f'<text x="{xx:.1f}" y="{yy:.1f}" font-size="{s}" fill="{f}" text-anchor="{anc}" font-weight="{w}"{tr}>{t}</text>')
def callout(n,x,y,bx,by,col="#c0392b"):
    # (x,y) точка на детали в мм, (bx,by) центр кружка в мм
    out.append(f'<line x1="{X(x):.1f}" y1="{Y(y):.1f}" x2="{X(bx):.1f}" y2="{Y(by):.1f}" stroke="{col}" stroke-width="2"/>')
    out.append(f'<circle cx="{X(x):.1f}" cy="{Y(y):.1f}" r="3.5" fill="{col}"/>')
    out.append(f'<circle cx="{X(bx):.1f}" cy="{Y(by):.1f}" r="17" fill="{col}" stroke="#fff" stroke-width="2.5"/>')
    out.append(f'<text x="{X(bx):.1f}" y="{Y(by)+6:.1f}" font-size="17" font-weight="bold" fill="#fff" text-anchor="middle">{n}</text>')

# --- корпус
rect(0,0,W,H,"#cfd8e3","#2c3e50",2,rx=5*sc)
rect(wall,wall,W-2*wall,H-2*wall,"#ffffff","#2c3e50",1.4)
for x0 in range(45,240,10): rect(x0,H-wall,3,wall,"#90a4ae","none",0)          # щели верхнего борта
rect(xc0-2,wall,2,H-2*wall,"#cfd8e3","#546e7a",1)                              # левая внутр. стенка
# --- отсек разъёмов монитора справа
rect(xc1,wall,W-wall-xc1,H-2*wall,"#eef8ef","#2e7d32",1.2,"6 4")
rect(xc1,9,2,75,"#fff8e1","#b8860b",1.6,"5 3")                                 # окно в стенке ниже полки
# --- бобышки M3
for x,ys in ((7,(7,76.7,146.4)),(265.2,(7,146.4))):
    for y in ys: circ(x,y,4.2,"#b0bec5"); circ(x,y,2,"#ffffff")
# --- контур монитора
rect(xc0+1,wall+1,237.2,145.4,"none","#7f8c8d",1.4,"10 6")
txt(60,146,"контур монитора — ложится сверху на полки",12,"#7f8c8d","start")
# --- кнопки монитора (на его задней панели)
for y,s in ((52,"−"),(70,"+"),(88,"⏻")): circ(23,y,3,"none","#9e9e9e",1.2,"3 2"); txt(23,y-1.4,s,12,"#757575")
# --- VESA
for x,y in ((70.1,26.7),(70.1,126.7),(170.1,26.7),(170.1,126.7)): circ(x,y,2.15,"#ffffff","#607d8b",1.5)
# --- зоны, которые нельзя занимать
rect(178.2,94.5,56,55.9,"#e8f5e9","#2e7d32",1.6,"7 5")
txt(206.2,128,"A",22,"#2e7d32",w="bold"); txt(206.2,120,"вилки USB / Ethernet",12,"#2e7d32"); txt(206.2,113,"55.9 мм",12,"#2e7d32")
rect(234.2,9,35,75,"#e8f5e9","#2e7d32",1.6,"7 5",op=0.85)
txt(244,72,"B",22,"#2e7d32",w="bold"); txt(244,64,"35 мм",12,"#2e7d32")
for y,col in ((29,"#f39c12"),(49,"#e74c3c"),(69,"#7f8c8d")): rect(251.2,y-3.5,4.5,7,col,"#5d4037",1.2)
txt(262.5,29,"Type-C",11,"#5d4037","middle",rot=-90); txt(262.5,49,"mini HDMI",11,"#5d4037","middle",rot=-90); txt(262.5,69,"наушн.",11,"#5d4037","middle",rot=-90)
txt(262.5,110,"разъёмы монитора",11,"#5d4037","middle",rot=-90)
rect(118.7,55,46.2,42,"#e8f5e9","#2e7d32",1.6,"7 5")
for x in (124.15,134.15,147.3,153.3,159.3): rect(x-1.1,60,2.2,26,"#eceff1","none",0)
txt(141.8,90.5,"C   сюда вдвигаются платы",13,"#2e7d32",w="bold")
# --- Raspberry Pi
px0,py0=178.2,7.0
rect(px0,py0,56,85,"#2e7d32","#1b5e20",1.6,rx=3*sc)
for x,y in ((181.7,10.5),(181.7,68.5),(230.7,10.5),(230.7,68.5)): circ(x,y,3.25,"#a5d6a7","#1b5e20",1); circ(x,y,1.2,"#1b5e20","none",0)
rect(179.4,14,4.8,51,"#212121","#000",1)                                       # GPIO 2x20
txt(186.5,40,"GPIO",11,"#e8f5e9","start",rot=-90)
txt(186.5,15.5,"пин 1",10,"#e8f5e9","start")
for y,lab,col in ((18.2,"USB-C","#f39c12"),(33,"µHDMI 0","#e74c3c"),(46.5,"µHDMI 1","#e74c3c"),(61,"аудио","#7f8c8d")):
    rect(231.7,y-3.5,4,7,col,"#333",1); txt(230.5,y-1.6,lab,11,"#ffffff","end")
for cx,w_,lab in ((225.2,13.1,"USB"),(207.2,13.1,"USB"),(188.45,16,"ETH")):
    rect(cx-w_/2,90,w_,4.5,"#cfd8dc","#37474f",1); txt(cx,97.5,lab,11,"#37474f")
rect(194,5.2,12,2.2,"#9e9e9e","#424242",0.8)                                   # microSD
txt(200,10,"microSD ↓",10,"#e8f5e9")
txt(206.2,80,"Raspberry Pi 4B",15,"#ffffff",w="bold")
# --- держатели
rect(141.6,4,23.3,49,"#c5cae9","#3949ab",1.2); rect(142.8,8,21,43,"#283593","#1a237e",1.2)
txt(153.3,47,"OUT",11,"#ffeb3b",w="bold"); txt(153.3,11,"IN",11,"#ffeb3b",w="bold")
txt(153.3,29,"DC-DC",13,"#ffffff",w="bold",rot=-90)
rect(118.7,4,21,40,"#c5cae9","#3949ab",1.2); rect(120.2,8,18,34,"#283593","#1a237e",1.2)
txt(129.2,38.5,"A B ⏚",10,"#ffeb3b",w="bold"); txt(129.2,11,"TTL",10,"#ffeb3b",w="bold")
txt(129.2,25,"RS485",13,"#ffffff",w="bold",rot=-90)
# --- панельные разъёмы нижнего борта и их тела внутри
rect(31-8.05,0,16.1,wall,"#ef6c00","#bf360c",1.2); rect(31-8.05,wall,16.1,13.5,"#ffe0b2","#e65100",1,"4 3")
rect(69-4.95,0,9.9,wall,"#ef6c00","#bf360c",1.2); rect(69-6,wall,12,17,"#ffe0b2","#e65100",1,"4 3")
rect(101-8.4,0,16.8,wall,"#ef6c00","#bf360c",1.2); rect(101-8,wall,16,21.6,"#ffe0b2","#e65100",1,"4 3")
for x,l in ((31,"XT60"),(69,"BNC"),(101,"RJ45")): txt(x,-6,l,14,"#bf360c",w="bold")
# --- выноски
callout(1,200,55,  171,76)
callout(2,158,34,  171.5,46)
callout(3,129.2,20, 108,62)
callout(4,31,10,    31,36)
callout(5,69,12,    58,40)
callout(6,101,14,   92,44)
callout(7,30,140,   30,118)
callout(8,256,49,   247,118)
callout(9,253.2,30, 244,100)
callout(10,7,76.7,  22,100)
callout(11,70.1,126.7, 86,110)
callout(12,23,70,   46,88)
# --- заголовок
out.insert(0,f'<text x="{ox}" y="48" font-size="30" font-weight="bold" fill="#111">Что куда встаёт</text>')
out.insert(1,f'<text x="{ox}" y="82" font-size="17" fill="#555">Вид со стороны экрана: монитор и лицевая рамка сняты, видна задняя стенка коробки. Корпус 272 x 153 x 59 мм.</text>')
out.insert(2,f'<text x="{ox}" y="108" font-size="17" fill="#555">Цифры — детали (расшифровка ниже), буквы A B C — зоны, которые должны остаться пустыми.</text>')
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

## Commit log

2026-09-20 Корпус SPRUT: параметрическая модель OpenSCAD, STL, документация по компонентам
    Коробка с открытым фронтом + лицевая рамка под 10.1" монитор, Raspberry Pi 4B,
    DC-DC 60V buck, RS485-TTL, XT60E-M, RJ45 и BNC. Размеры Pi 4B и XT60E-M —
    по официальным чертежам; монитор и DC-DC заданы параметрами с пометкой
    «уточнить». Оба STL проверены на замкнутость.
    Claude-Session: https://claude.ai/code/session_011wwgPrf3yNj7Yf3HdnQxoy
    [sprut_bezel.stl, sprut_box.stl, sprut_korpus.scad]
2026-09-20 Монитор по замеру: 237.2 x 145.4 x 14.5, пересобраны STL и документация
    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
    [sprut_bezel.stl, sprut_box.stl, sprut_korpus.scad]
2026-09-20 Разрезы крепления монитора, опция section_y и генератор 2D-сечений
    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
    [slice.scad, sprut_korpus.scad]
2026-09-20 Стенки боковых каналов на всю высоту: фиксация монитора по X; скрипт проверки размеров STL
    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
    [sprut_box.stl, sprut_korpus.scad]
2026-09-20 Raspberry Pi полностью внутри корпуса: окно портов убрано, зазор 35 мм под кабели, вентиляция
    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
    [sprut_box.stl, sprut_korpus.scad]
2026-09-20 Отсек под боковые разъёмы монитора: угловые HDMI/Type-C, окно во внутренней стенке, 7 бобышек
    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
    [sprut_bezel.stl, sprut_box.stl, sprut_korpus.scad]
2026-09-20 Разрез через боковой разъём монитора, макет угловых штекеров
    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
    [slice.scad, sprut_korpus.scad]
2026-09-21 Pi придвинута к борту, порты выходят наружу через окно; расширены пазы держателей плат
    Окно 54.3 x 20.1 мм под 4xUSB и Ethernet: штекеры втыкаются снаружи и не
    занимают места внутри корпуса. Просвет пазов держателей увеличен до
    плата + 0.9 мм, добавлена заходная фаска 4 мм на открытом конце.
    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
    [sprut_bezel.stl, sprut_box.stl, sprut_korpus.scad]
2026-09-21 Pi полностью внутри: плата прижата к дальнему борту, перед разъёмами 58.4 мм под вилки
    Возврат к закрытой компоновке без окна в борту. Плата сдвинута к верхнему
    борту стороной microSD, вся оставшаяся высота полости отдана под вилки USB
    и Ethernet. Добавлена схема компоновки preview/layout_top.png.
    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
    [sprut_bezel.stl, sprut_box.stl, sprut_korpus.scad]
2026-09-21 Отсек разъёмов очищен: стенка только до полки, бобышки по углам, фиксация монитора ребром рамки
    Со стороны боковых разъёмов монитора на его уровне убраны внутренняя стенка
    и средние бобышки — штекер проходит вдоль всего торца. Монитор по X держит
    ребро 2.5 мм на лицевой рамке, выше штекера. Держатель DC-DC возвращён к
    первой версии (просвет 21.35), у RS485 зазоры остались расширенными.
    Co-Autho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
    [sprut_bezel.stl, sprut_box.stl, sprut_korpus.scad]
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2026-09-21 Монитор KEPIFO JRP1133: порты на правом торце — отсек справа, Pi слева, прорезь под колёсико
    По фото производителя (Daraz, код JRP1133-DCT) определены сторона и координаты
    разъёмов: правый торец, от нижнего края HDMI 62, Type-C 79, колёсико 94,
    Type-C 124. Компоновка отражена: отсек и окно под кабели справа, Raspberry Pi
    слева портами к верхнему борту (58.4 мм под вилки), держатели и панельные
    разъёмы сдвинуты в середину,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
    [sprut_bezel.stl, sprut_box.stl, sprut_korpus.scad]
2026-09-21 Монитор Display-A по фото владельца: Type-C 25, mini HDMI 45, наушники 65 мм; прорезь под колёсико убрана
    Точный вариант платы найден на Яндекс Маркете. Один Type-C (питание + тач),
    mini HDMI, гнездо наушников на правом торце; сенсорные кнопки на задней
    панели. Окно под кабели сдвинуто на 12–80 мм от нижнего края, wheel_slot
    отключён. Фото KEPIFO JRP1133 оставлены как другой вариант.
    Claude-Sessi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
    [sprut_bezel.stl, sprut_box.stl, sprut_korpus.scad]
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2026-09-22 Держатели DC-DC и RS485 компактным блоком у нижнего борта в правом нижнем углу
    Платы стоят вдоль высоты корпуса и вдвигаются сверху; до правой внутренней
    стенки 11 мм под кабели из отсека, отверстие VESA свободно, вентиляция
    перенесена слева от блока.
    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
    [sprut_box.stl, sprut_korpus.scad]
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2026-09-23 Raspberry Pi у стенки со стороны разъёмов монитора, держатели левее Pi
    Pi перенесена к правой стенке (pi_near_bay): micro-HDMI и USB-C смотрят в
    окно отсека напротив mini HDMI и Type-C монитора, HDMI-шлейф ~10 см. Окно
    в стенке расширено до 5–80 мм от нижнего края. Зазор под microSD увеличен
    до 4 мм (карта выступает за плату). Держатели DC-DC и RS485 блоком у
    нижнего борта левее Pi и отверстия VESA.
    Clau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
    [sprut_bezel.stl, sprut_box.stl, sprut_korpus.scad]
2026-09-23 35 мм перед micro-HDMI/USB-C Raspberry Pi, VESA сдвинут с платы
    Pi отодвинута от стенки отсека: от торца micro-HDMI до наружного борта 35 мм
    (параметр pi_hdmi_free), влезает и прямой штекер с хвостовиком. Нижнее правое
    отверстие VESA оказалось под выводами GPIO — крепление сдвинуто на 16 мм
    влево (vesa_dx). Держатели сдвинуты вслед, вентиляция перенесена над ними.
    Claude-Session: https://claude.ai/code/session_01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
    [sprut_bezel.stl, sprut_box.stl, sprut_korpus.scad]
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
